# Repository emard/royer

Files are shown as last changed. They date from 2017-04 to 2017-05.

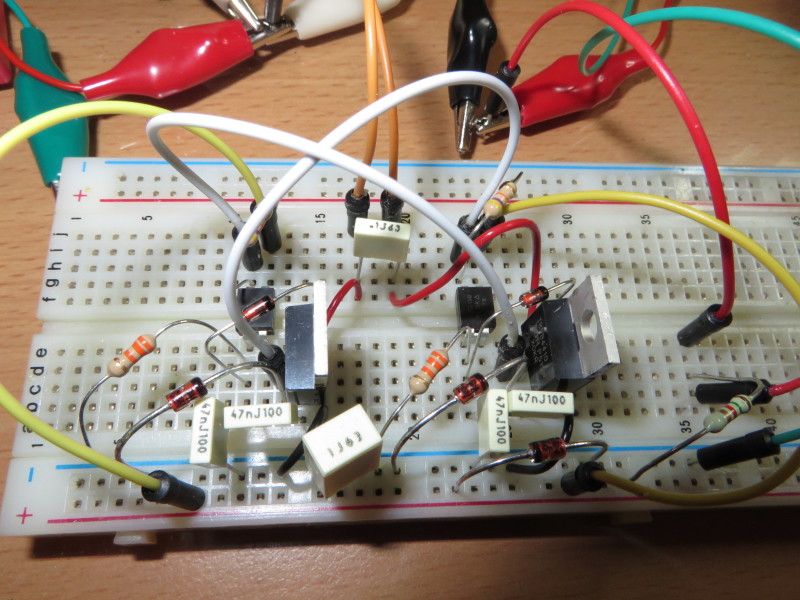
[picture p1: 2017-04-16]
MOSFET-24V/pic/protoboard.jpg

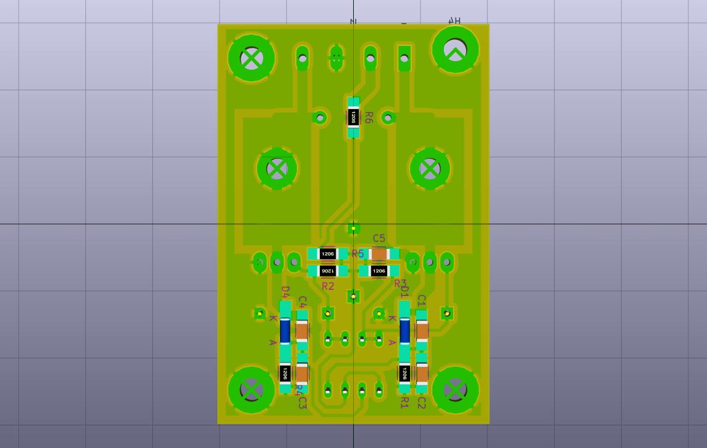
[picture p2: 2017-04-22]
MOSFET-24V/pic/mos3db.jpg

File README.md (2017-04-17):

# Royer - simple sinewave oscillator

Schematics and some PCBs practice in kicad
with several variations (BJT, MOSFET, IGBT)
of simple sinewave oscillators, initially 
published by:

    George H. Royer
    Electrical Manufacturing
    December 1954

Royer oscillator uses zero-voltage switching
(ZVS) to the parallel LC resonant circuit. 
Voltage at LC is sinewave when oscillator is unloaded.
More load will more deform the sinewave.

About regulated Royer see:

    Jim Williams
    Linear Technology
    Application note 118
    March 2008

It needs a sufficiently large choke in series
with middle turn of resonant L. If muddle turn is
not available then 2 chokes can be used.

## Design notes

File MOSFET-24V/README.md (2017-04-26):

# Low voltage Royer with MOSFET

Using low treshold MOSFETs for supply voltage 9-24V
Schematics starts with supply voltage above 8V.

Supply voltage and recommended max amperage:

     9V 0.5A
    12V 1-0A
    24V 2.0A

Avoid running at low voltage supply voltage <15V and high current
>2A because mosfets gate voltage will not be as steep to quicky
switch therefore they will heat up significantly.

At higher supply voltage, >24V mosfets swich faster and
dissiapte less heat.

The slope of the primary coil of transformer is approx the same
as gate slope. Primary coil amplitude is about 2-3x the supply
voltage. Take into account increased voltage at primary when 
choosing voltage rating for mosfets, capactors and fast diodes.

# PCB

Gerber files can be uploaded to https://www.seeedstudio.com/fusion_pcb.html
they will produce PCB for 10$

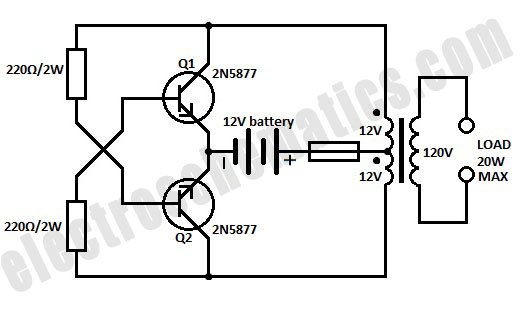
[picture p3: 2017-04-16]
BJT-12V/pic/12vdc-120vac-inverter.jpg

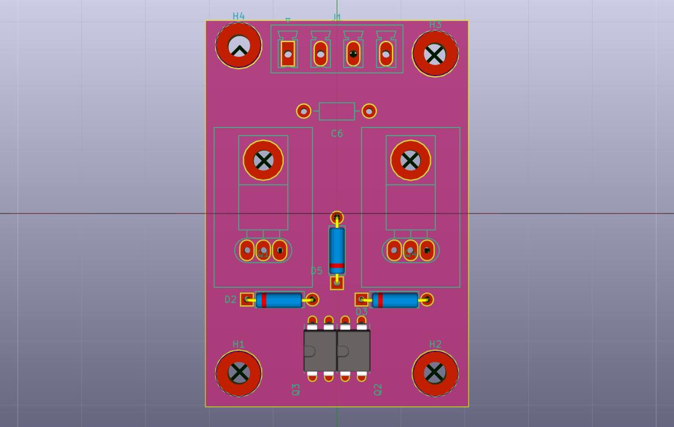
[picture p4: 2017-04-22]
MOSFET-24V/pic/mos3dt.jpg

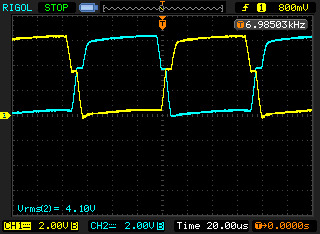
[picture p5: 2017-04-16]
MOSFET-24V/scope/prototype/gates7.5V.jpg

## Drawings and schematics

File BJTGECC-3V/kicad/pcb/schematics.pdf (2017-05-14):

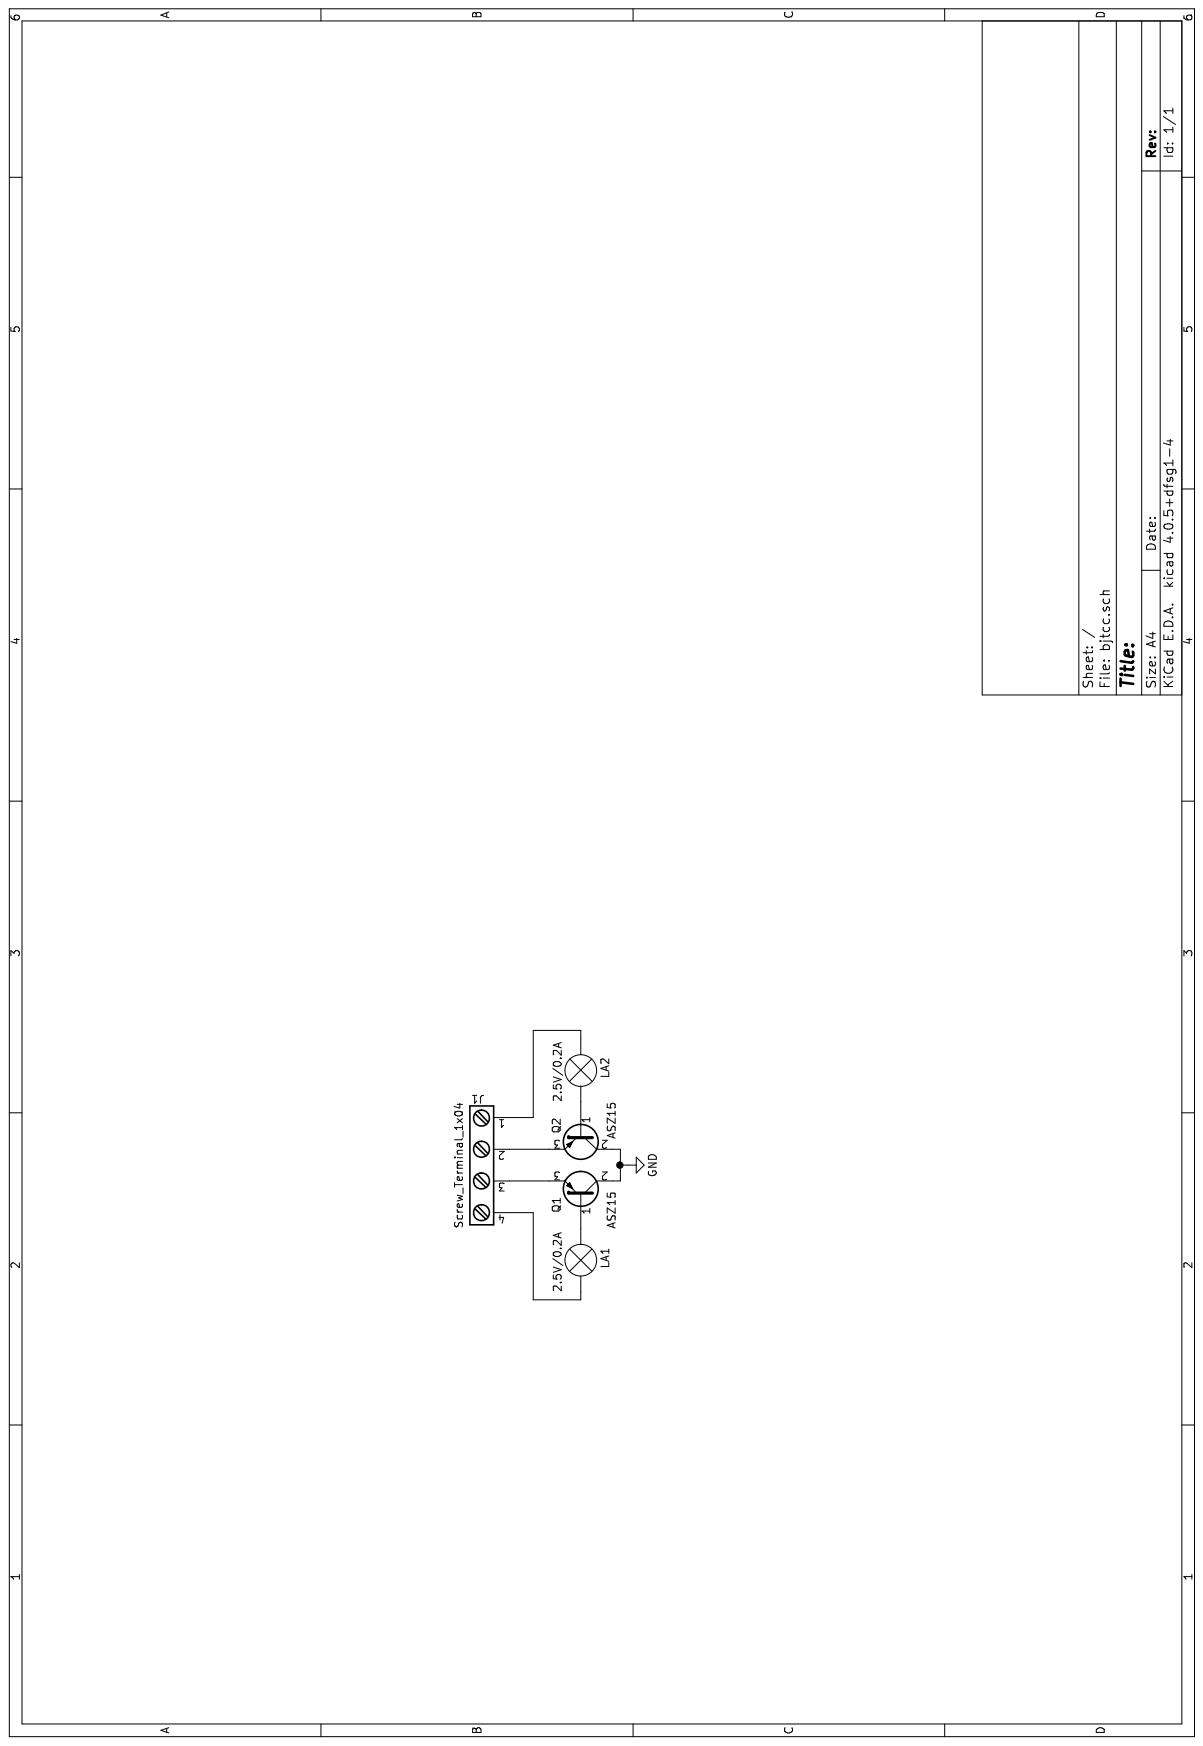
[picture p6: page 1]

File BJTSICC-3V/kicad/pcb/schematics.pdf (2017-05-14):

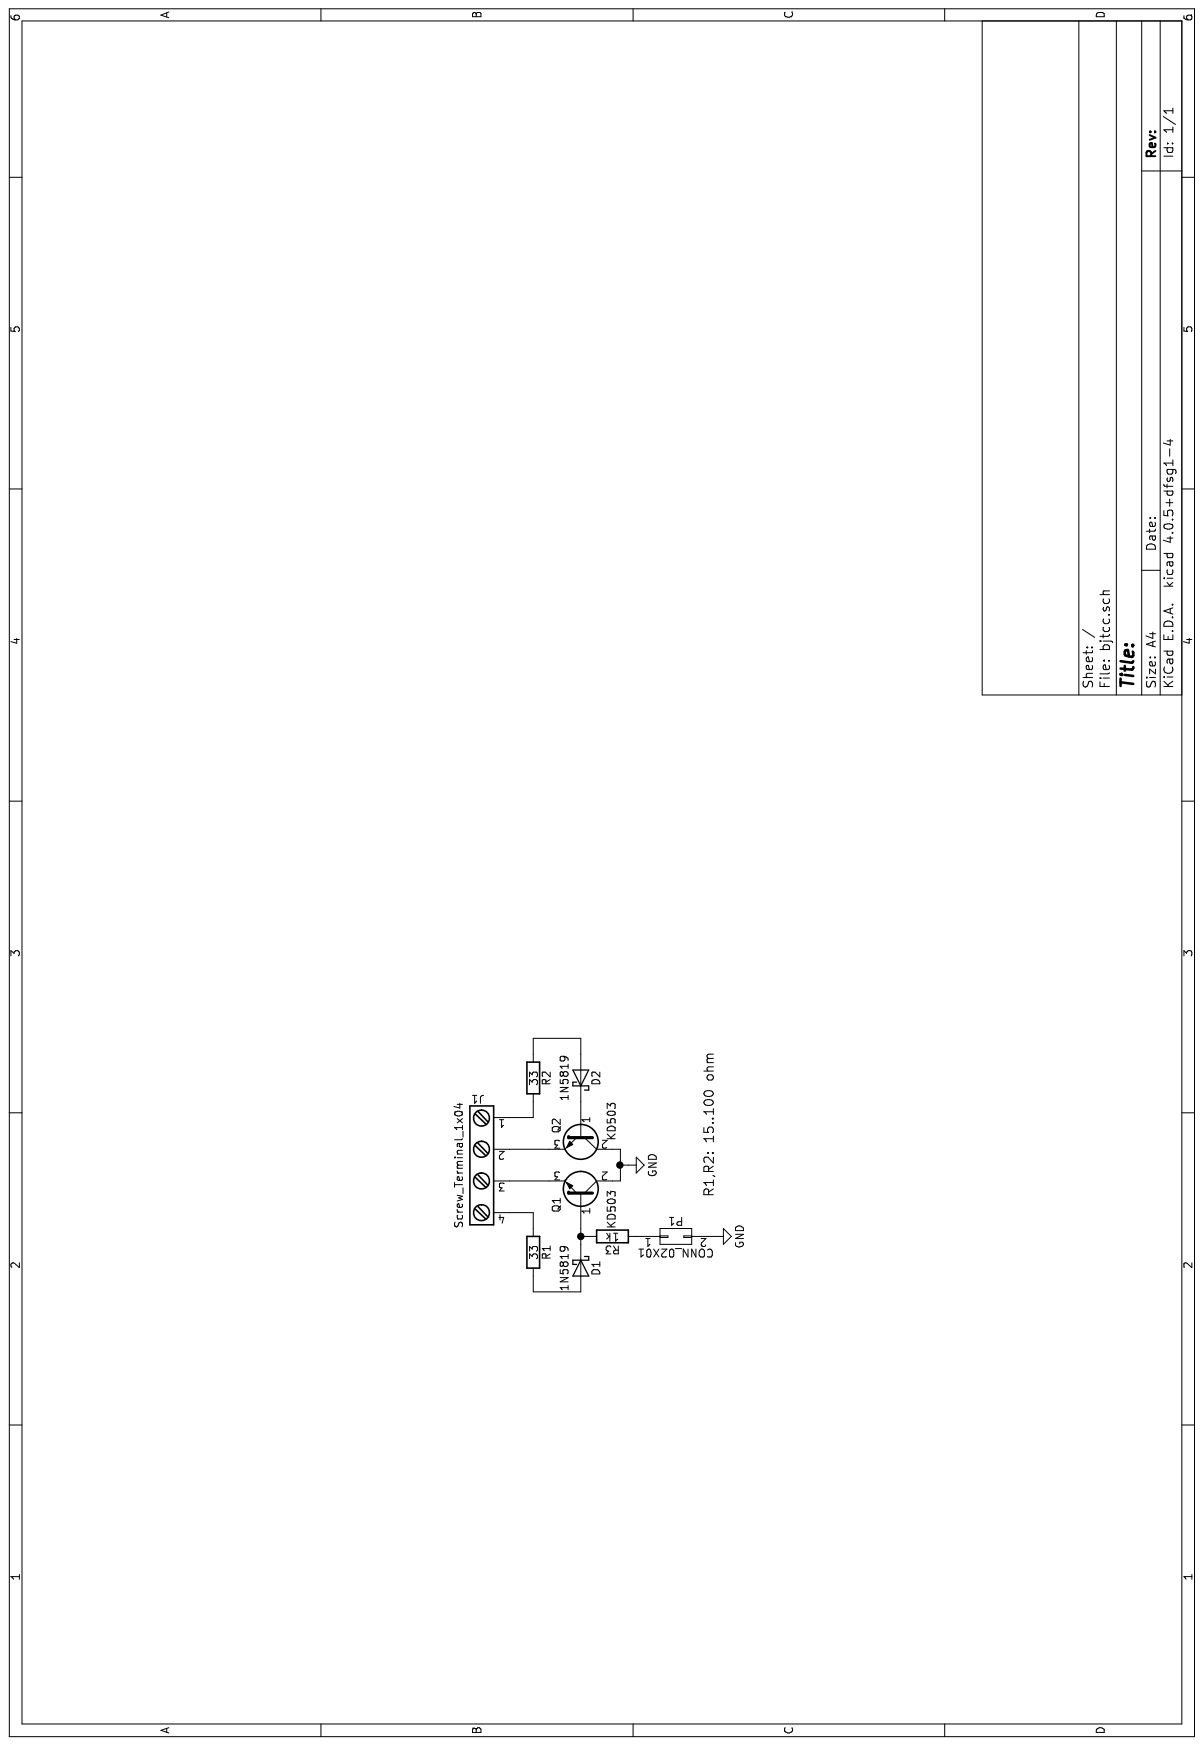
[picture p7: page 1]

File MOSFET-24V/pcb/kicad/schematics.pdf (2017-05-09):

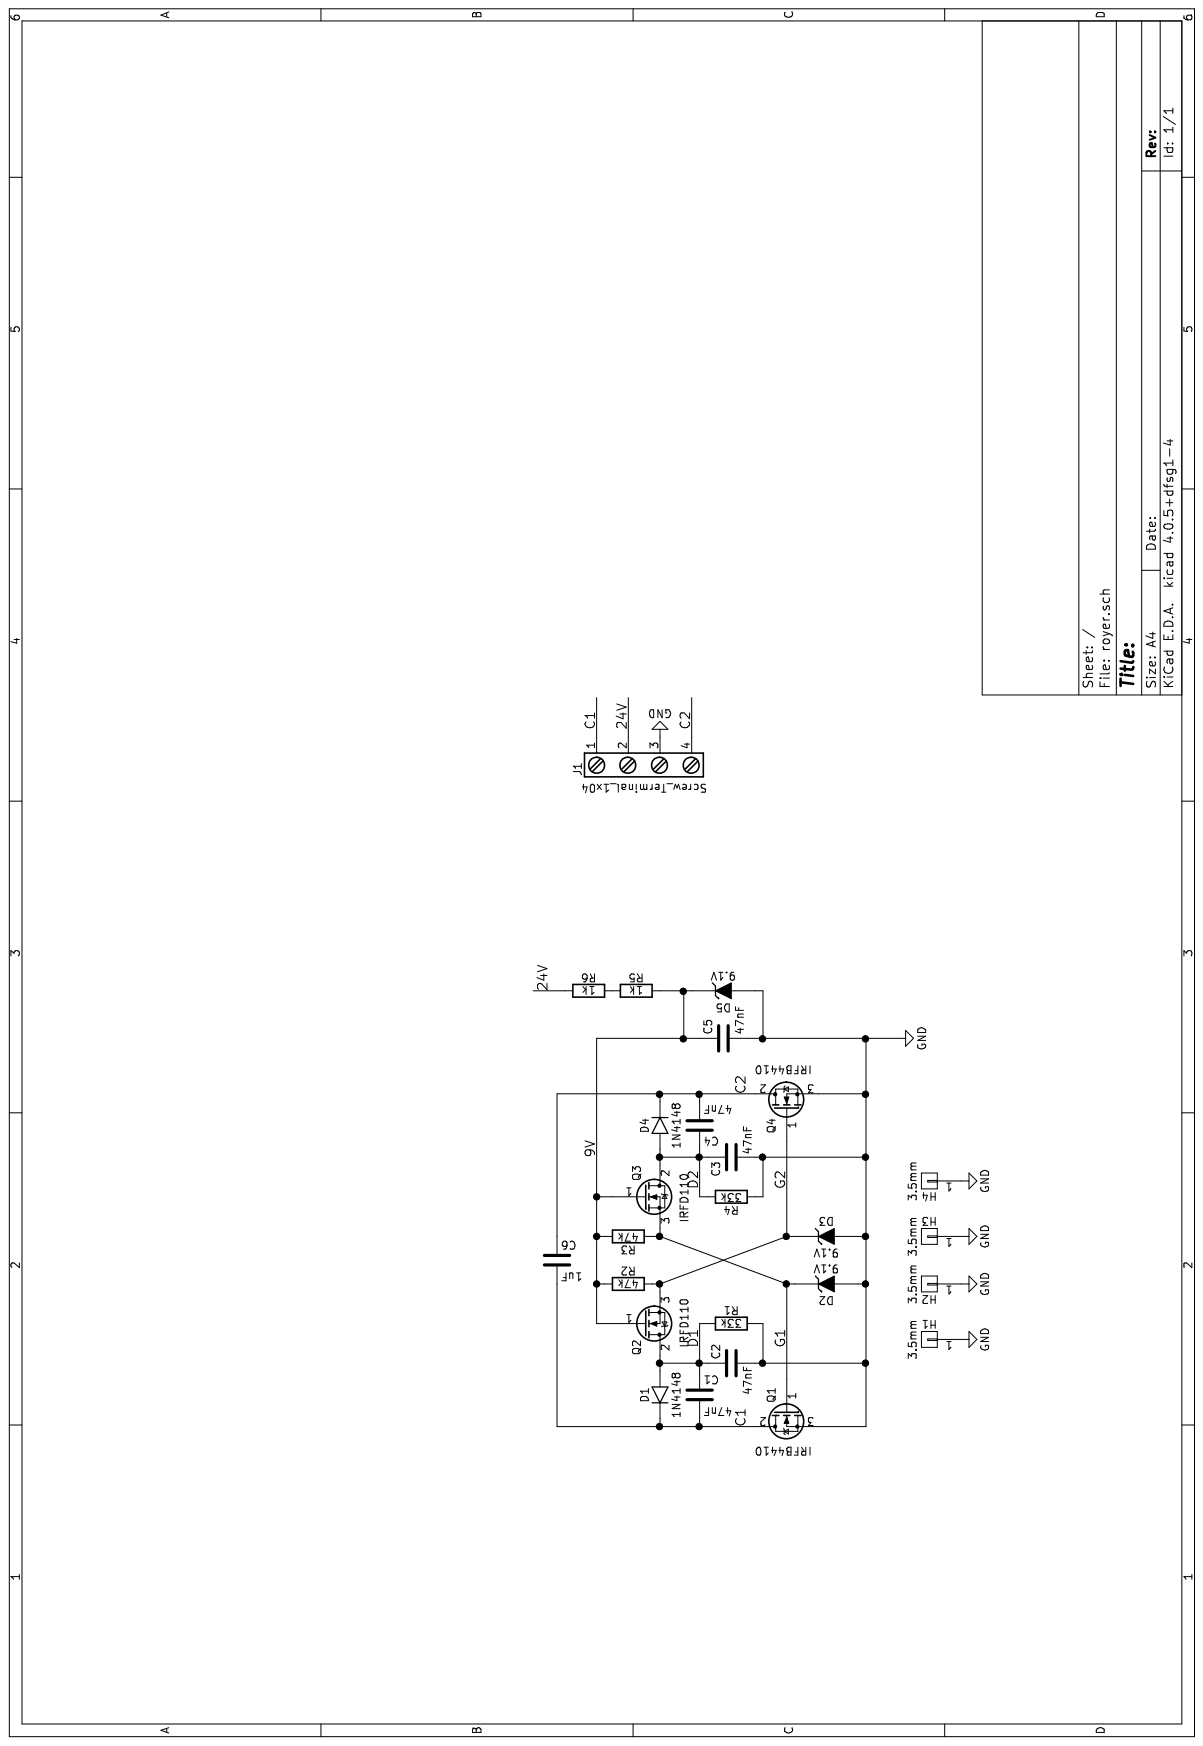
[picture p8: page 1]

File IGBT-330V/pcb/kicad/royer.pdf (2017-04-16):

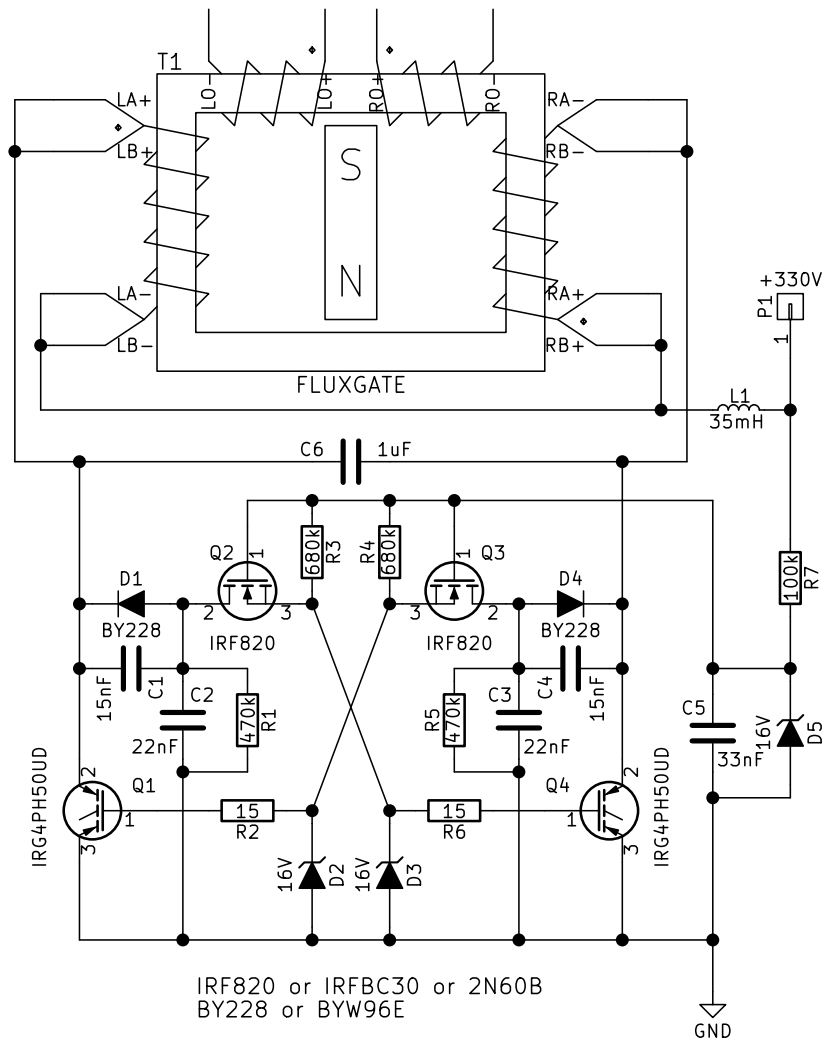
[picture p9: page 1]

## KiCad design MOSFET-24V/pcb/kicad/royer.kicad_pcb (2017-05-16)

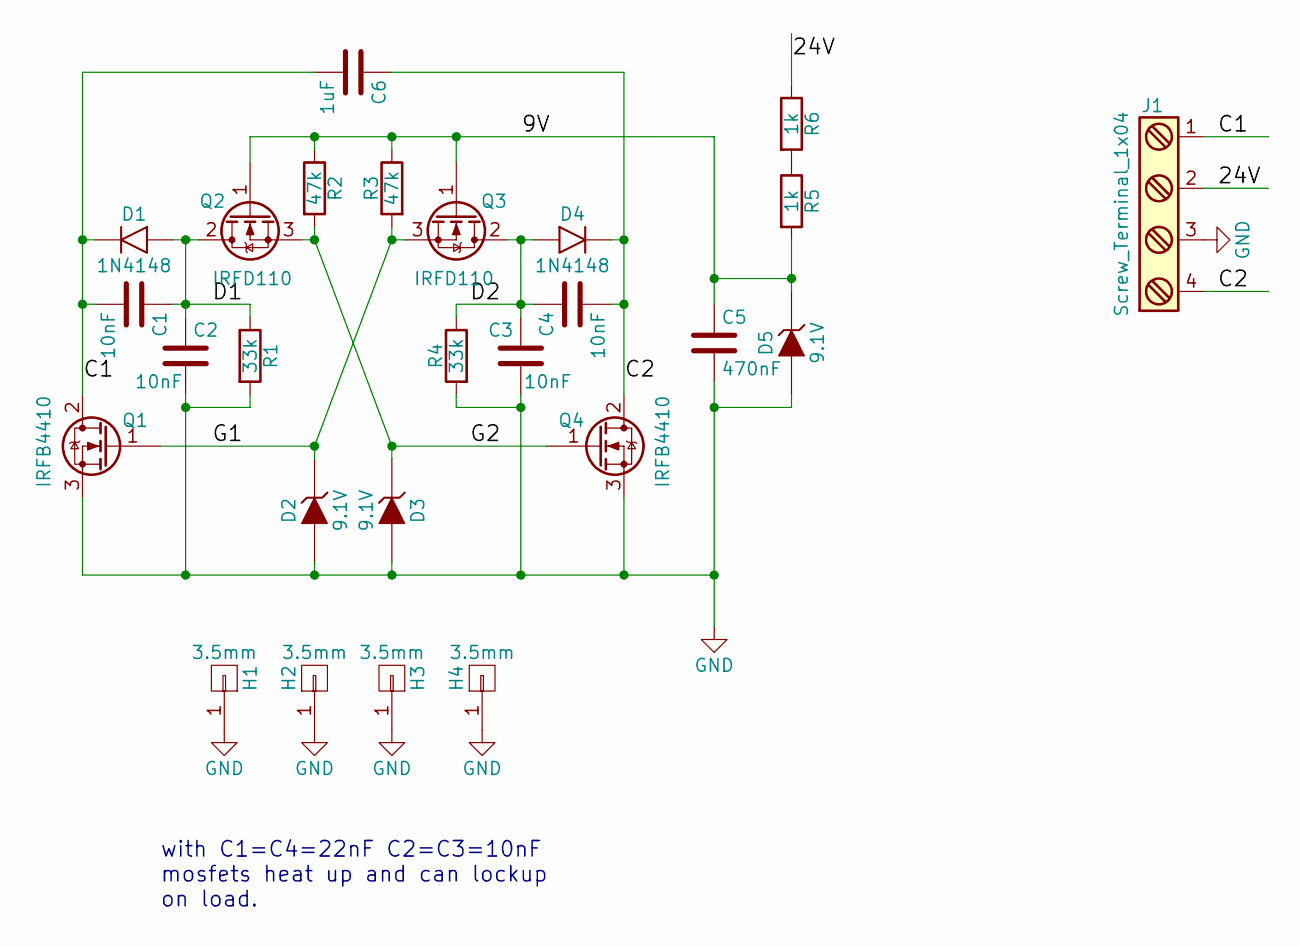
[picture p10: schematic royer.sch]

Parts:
C1, C2, C3, C4: 10nF; C_1206_HandSoldering
C5: 470nF; C_1206_HandSoldering
C6: 1uF; Choke_Horizontal_RM10mm
D1, D4: 1N4148; MiniMELF_Handsoldering
D2, D3, D5: 9.1V; D4
H1, H2, H3, H4: 3.5mm; MountingHole_3.5mm_Pad
J1: Screw_Terminal_1x04; screw-terminal-4-pin
Q1, Q4: IRFB4410; TO-220-small-heatsink
Q2, Q3: IRFD110; DIP-4_W7.62mm_LongPads
R1, R4: 33k; R_1206_HandSoldering
R2, R3: 47k; R_1206_HandSoldering
R5, R6: 1k; R_1206_HandSoldering

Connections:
/9V: C5.1, D5.1 (K), Q2.1 (G), Q3.1 (G), R2.1, R3.1, R5.2
/24V: J1.2, R6.1
/C1: C1.2, C6.2, D1.1 (K), J1.1, Q1.2 (D)
/C2: C4.2, C6.1, D4.1 (K), J1.4, Q4.2 (D)
/D1: C1.1, C2.1, D1.2 (A), Q2.2 (D), R1.1
/D2: C3.1, C4.1, D4.2 (A), Q3.2 (D), R4.1
/G1: D2.1 (K), Q1.1 (G), Q3.3 (S), R3.2
/G2: D3.1 (K), Q2.3 (S), Q4.1 (G), R2.2
GND: C2.2, C3.2, C5.2, D2.2 (A), D3.2 (A), D5.2 (A), H1.1, H2.1, H3.1, H4.1, J1.3, Q1.3 (S), Q4.3 (S), R1.2, R4.2
unnamed: R5.1, R6.2

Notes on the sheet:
with C1=C4=22nF C2=C3=10nF mosfets heat up and can lockup on load.

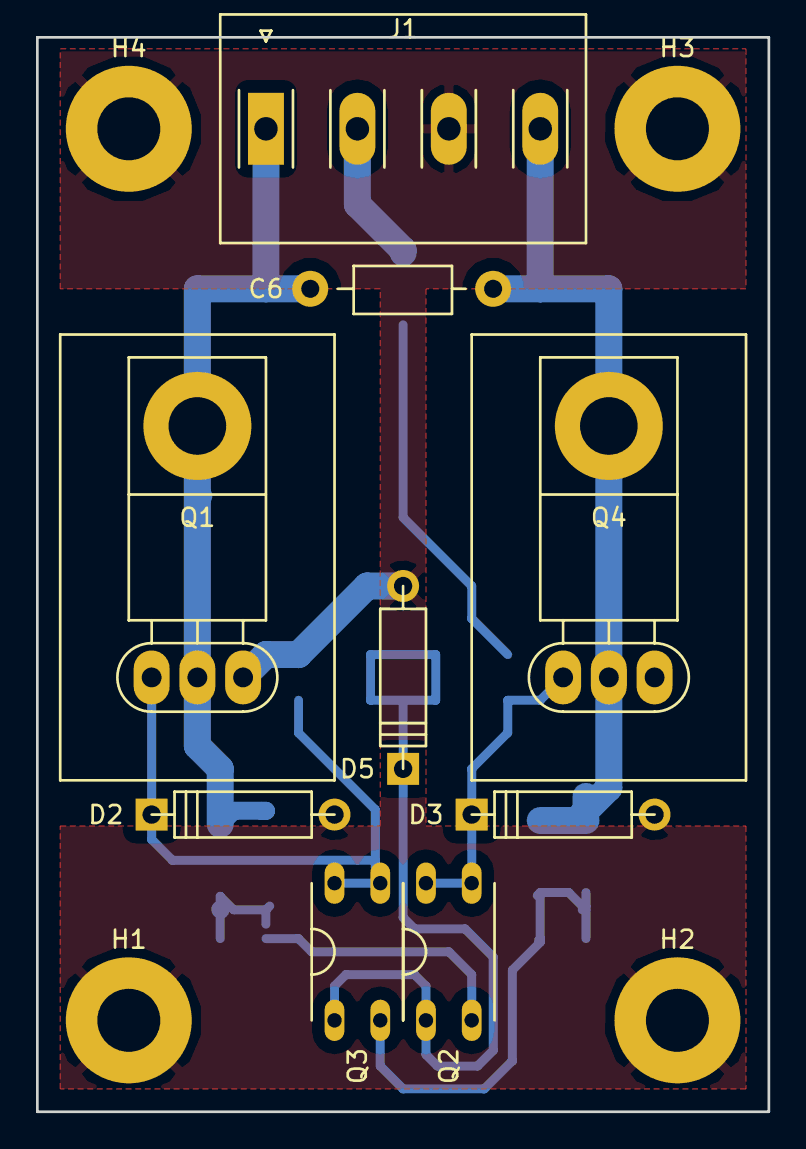
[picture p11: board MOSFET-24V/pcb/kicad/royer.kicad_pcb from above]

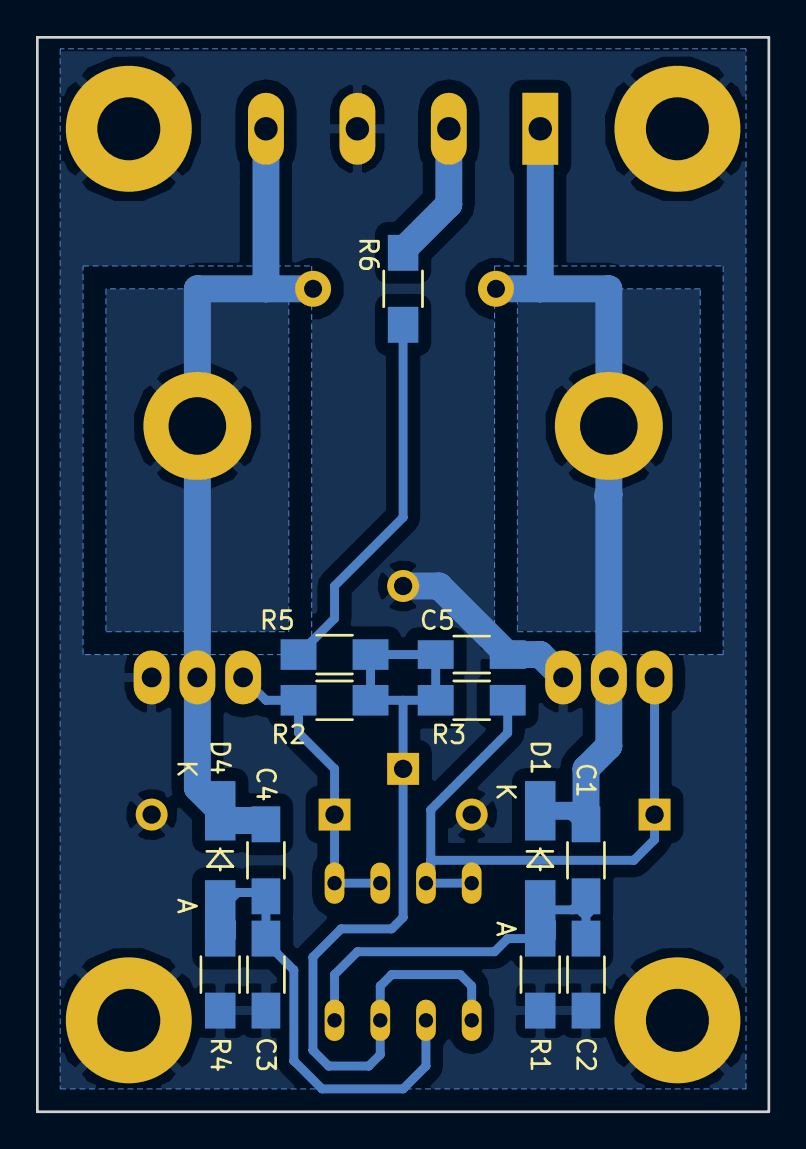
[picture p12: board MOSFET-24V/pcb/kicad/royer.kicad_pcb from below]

Board: 2 copper layers, 40.6 x 59.7 mm, 26 parts (13 on the bottom side), 10 nets.

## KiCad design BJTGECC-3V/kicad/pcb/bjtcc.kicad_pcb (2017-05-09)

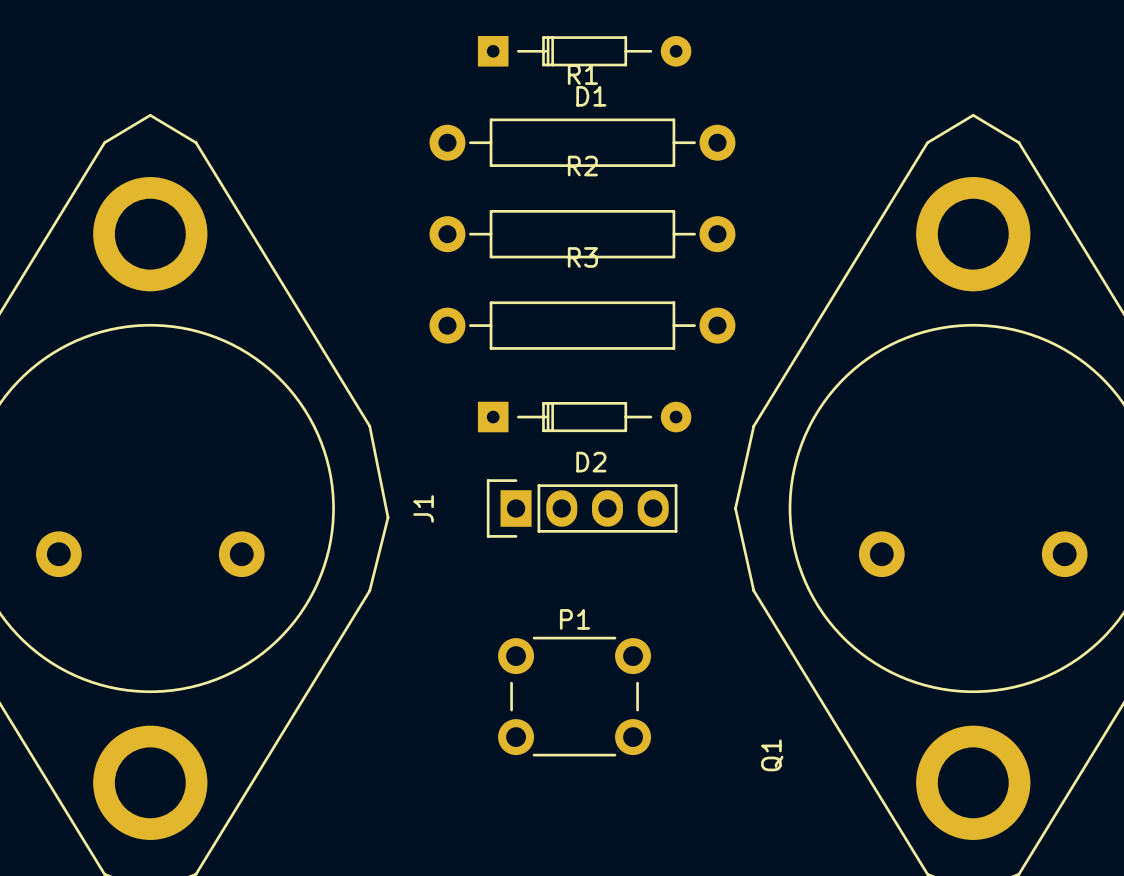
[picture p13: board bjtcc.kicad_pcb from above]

Board: 2 copper layers, 9 parts (0 on the bottom side), 10 nets, no tracks yet.

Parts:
D1, D2: 1N5819; Diode_DO-35_SOD27_Horizontal_RM10
J1: Screw_Terminal_1x04; Pin_Header_Straight_1x04
P1: CONN_02X01; SW_PUSH_6mm_h5mm
Q1, Q2: ASZ15; TO3
R1, R3: 47; Resistor_Horizontal_RM15mm
R2: 1k; Resistor_Horizontal_RM15mm

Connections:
GND: P1.2, Q1.2, Q2.2
unnamed: D1.1, R1.2
unnamed: D1.2, Q1.1, R2.2
unnamed: D2.1, R3.2
unnamed: D2.2, Q2.1
unnamed: J1.1, R3.1
unnamed: J1.2, Q2.3
unnamed: J1.3, Q1.3
unnamed: J1.4, R1.1
unnamed: P1.1, R2.1

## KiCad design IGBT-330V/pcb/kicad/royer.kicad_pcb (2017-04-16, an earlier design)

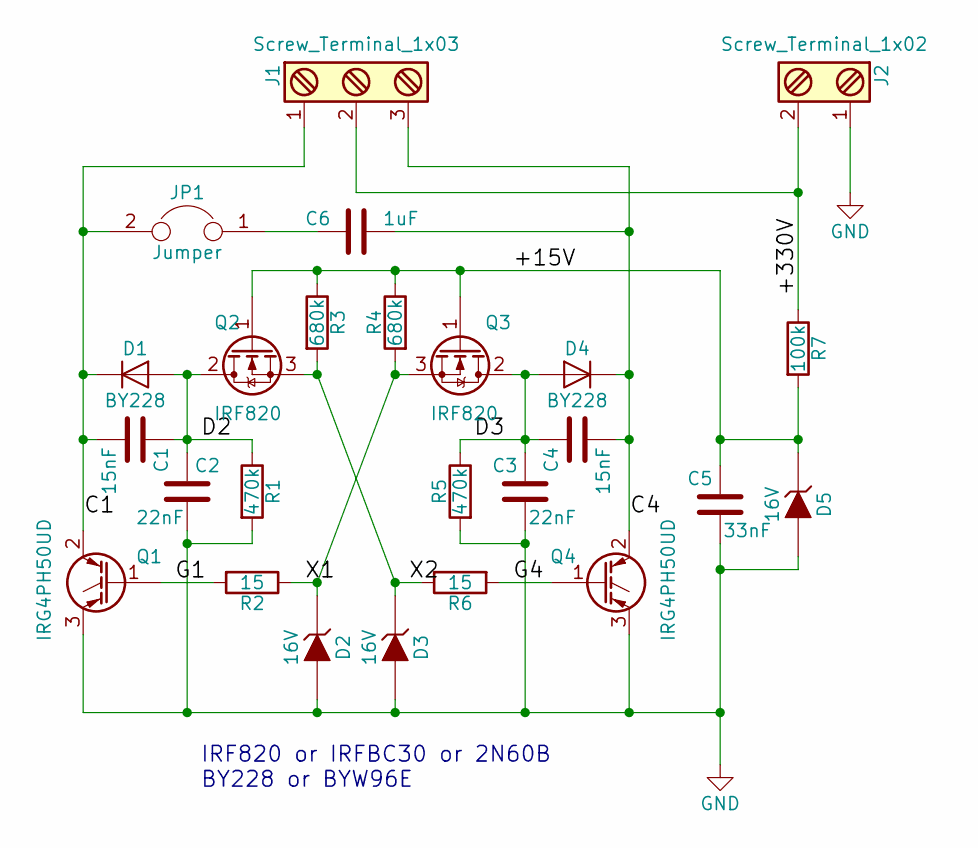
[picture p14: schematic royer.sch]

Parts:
C1, C4: 15nF; C_Rect_L27_W9_H17_P23
C2, C3: 22nF; C_Rect_L27_W9_H17_P23
C5: 33nF; C_Rect_L27_W9_H17_P23
C6: 1uF; C_Rect_L27_W9_H17_P23
D1, D4: BY228; Diode_DO-201AD_Horizontal_RM15
D2, D3, D5: 16V; D6
J1: Screw_Terminal_1x03; TerminalBlock_WAGO-804_RM5mm_3pol
J2: Screw_Terminal_1x02; TerminalBlock_WAGO-804_RM5mm_2pol
JP1: Jumper; TerminalBlock_Pheonix_MPT-2.54mm_2pol
Q1, Q4: IRG4PH50UD; TO-247_Vertical_Neutral123_largePads
Q2, Q3: IRF820; TO-220_Neutral123_Vertical_LargePads
R1, R5: 470k; Resistor_Horizontal_RM15mm
R2, R6: 15; Resistor_Horizontal_RM20mm
R3, R4: 680k; Resistor_Horizontal_RM15mm
R7: 100k; Resistor_Horizontal_RM15mm

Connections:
/+15V: C5.1, D5.1 (K), Q2.1 (G), Q3.1 (G), R3.1, R4.1, R7.2
/+330V: J1.2, J2.2, R7.1
/C1: C1.2, D1.1 (K), J1.1, JP1.2, Q1.2 (C)
/C4: C4.2, C6.1, D4.1 (K), J1.3, Q4.2 (C)
/D2: C1.1, C2.1, D1.2 (A), Q2.2 (D), R1.1
/D3: C3.1, C4.1, D4.2 (A), Q3.2 (D), R5.1
/G1: Q1.1 (G), R2.2
/G4: Q4.1 (G), R6.2
/X1: D2.1 (K), Q3.3 (S), R2.1, R4.2
/X2: D3.1 (K), Q2.3 (S), R3.2, R6.1
GND: C2.2, C3.2, C5.2, D2.2 (A), D3.2 (A), D5.2 (A), J2.1, Q1.3 (E), Q4.3 (E), R1.2, R5.2
unnamed: C6.2, JP1.1

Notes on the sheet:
IRF820 or IRFBC30 or 2N60B BY228 or BYW96E

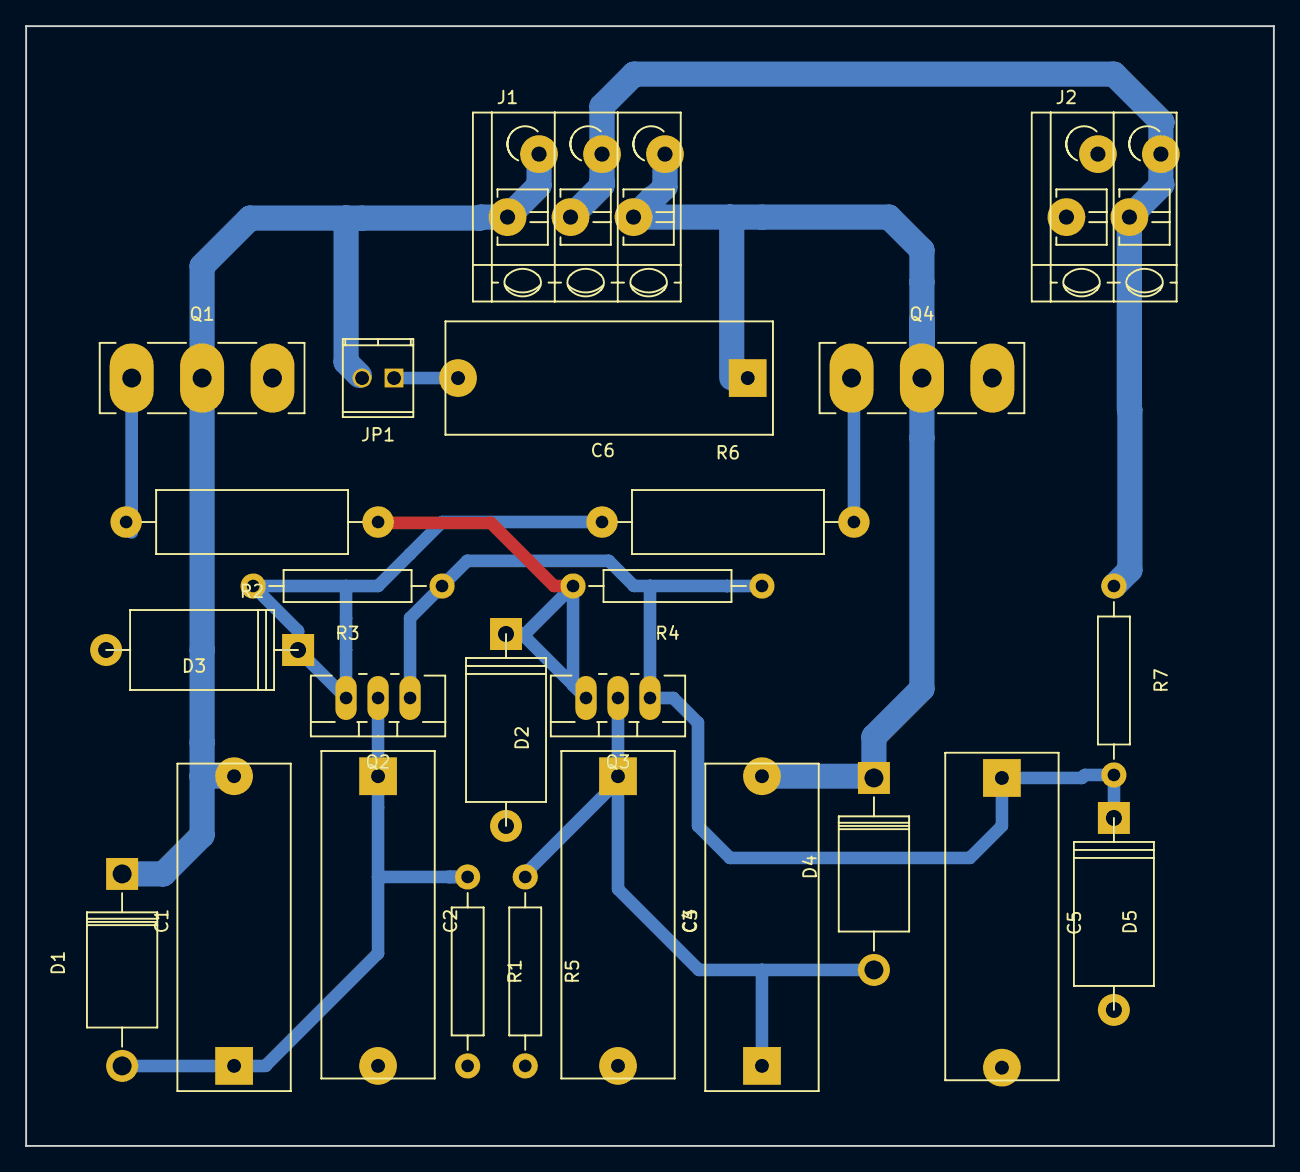
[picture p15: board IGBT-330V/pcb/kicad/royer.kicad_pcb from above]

Board: 2 copper layers, 99.1 x 88.9 mm, 25 parts (0 on the bottom side), 12 nets.

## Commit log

2017-04-16 simple schematics of basic royer oscillator with BJT transistors
2017-04-16 Low voltage MOSFET 9-24V
    [royer.kicad_pcb, royer.sch]
2017-04-16 high voltage IGBT 30-330V
    [royer.kicad_pcb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]
2017-04-16 move kicad to PCB subdirectory
    [royer.kicad_pcb, royer.sch]
2017-04-16 net labels
    [royer.kicad_pcb, royer.sch]
2017-04-16 rearranging SMD components
    [royer.kicad_pcb, royer.sch]
2017-04-16 fixing GND on the schematics
    [royer.kicad_pcb, royer.sch]
2017-04-16 better component placement, single-sided PCB
    [royer.kicad_pcb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]
2017-04-16 symmetry on the PCB
    [royer.kicad_pcb, royer.sch]
2017-04-16 gerber update
    [royer-B.Cu.gbr, royer-B.Fab.gbr, royer-B.Mask.gbr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]
2017-04-16 rearranging components, routed
    [royer.kicad_pcb, royer.sch]
2017-04-17 optimizing component placement
    [royer.kicad_pcb, royer.sch]
2017-04-17 correct footprint for DIL-4 power mosfet
2017-04-17 stack DIL-4 end-to-end to fit into a single DIL-8 socket
    [royer.kicad_pcb, royer.sch]
2017-04-17 compacting PCB
    [royer.kicad_pcb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]
2017-04-17 enlarging holes 3.2->3.5 mm# Please enter the commit message for your changes. Lines starting
    [royer.kicad_pcb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]
2017-04-22 footprint for small TO-220 heatsink
    [royer.kicad_pcb, royer.sch]
2017-04-22 compacting PCB (using only 4 screw terminals)
    [royer.kicad_pcb, royer.sch]
2017-04-22 updating gerbers
    [royer-B.Cu.gbr, royer-B.Fab.gbr, royer-B.Mask.gbr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]
2017-04-22 git add TO-220 footprint with small heatsing (late commit)
2017-04-22 increasing drill hole sizes in to-220 and screw terminal footprints
    [royer.kicad_pcb, royer.sch]
2017-04-22 plot to seeedstudio rules
    [royer.kicad_pcb]
2017-04-23 small changes to reflect production
    [royer.kicad_pcb]
2017-04-23 board send to production
    [royer-B.Cu.gbl, royer-B.Mask.gbs, royer-B.SilkS.gbo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]
2017-04-23 last minute change (too late for production) TO-220 pads placed only on bottom layer to avoid short-circuit with mounted heatsink
    [royer.kicad_pcb]
2017-04-26 PCB production
    [royer-B.Cu.gbl, royer-B.Mask.gbs, royer-B.SilkS.gbo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]
2017-04-27 pcb fill layer not rebuild after hole repositioned. It is now corrected and top GND layer is added. Sent to production
    [royer-B.Cu.gbl, royer-B.Mask.gbs, royer-B.SilkS.gbo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]
2017-05-09 initial commit of BJT common-collector schematics
    [bjtcc.kicad_pcb, bjtcc.sch]
2017-05-09 rough placing footprints on PCB
    [bjtcc.kicad_pcb, bjtcc.sch]
2017-05-09 moving to "pcb" directory
    [bjtcc.kicad_pcb, bjtcc.sch]
2017-05-09 schematics PDF
2017-05-09 moving to "kicad/pcb" directory
    [bjtcc.kicad_pcb, bjtcc.sch]
2017-05-14 BJT version with Si and Ge
    [bjtcc.kicad_pcb, bjtcc.sch]
2017-05-15 changing values on MOSFET circuit
    [royer.sch]
2017-05-16 Change from 10nF/10nF to 22nF/10nF capacitive divider
    [royer.kicad_pcb, royer.sch]
2017-05-16 revert back to 10nF
    [royer.kicad_pcb, royer.sch]
2017-05-16 gerbers update
    [royer-B.Cu.gbl, royer-B.Mask.gbs, royer-B.SilkS.gbo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]
2017-05-18 Cn 22nF comment
    [royer.sch]
